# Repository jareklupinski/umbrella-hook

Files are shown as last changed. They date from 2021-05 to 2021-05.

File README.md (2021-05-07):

# umbrella-hook
Umbrella hook is a wall-mounted umbrella docking solution that interacts with AI-enhanced Weather Forecasting Services to notify the user of impending sky hydration by emitting a pleasing blue glow.

The intention is that as you glance at your umbrella on your way out the door, if the umbrella-hook is blue, you grab your umbrella.

## How it works

Umbrella-hook contains a small circuit board running a simple program that:
- Offers an interface for connecting umbrella-hook to a WiFi router and setting the umbrella-hook location
- Makes a GET request with the provided location to an API that responds with whether there will be rain in that area, and in how many hours

The umbrella-hook then turns on the on-board LED if the returned hours value overlaps the user's chosen "Rain Warning Time" (default to 6 hours).

Housing:

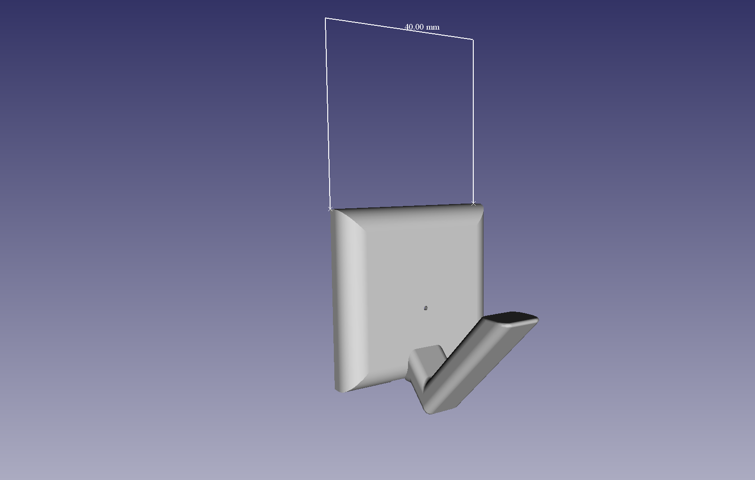
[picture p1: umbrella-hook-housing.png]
housing


Housing Wireframe:

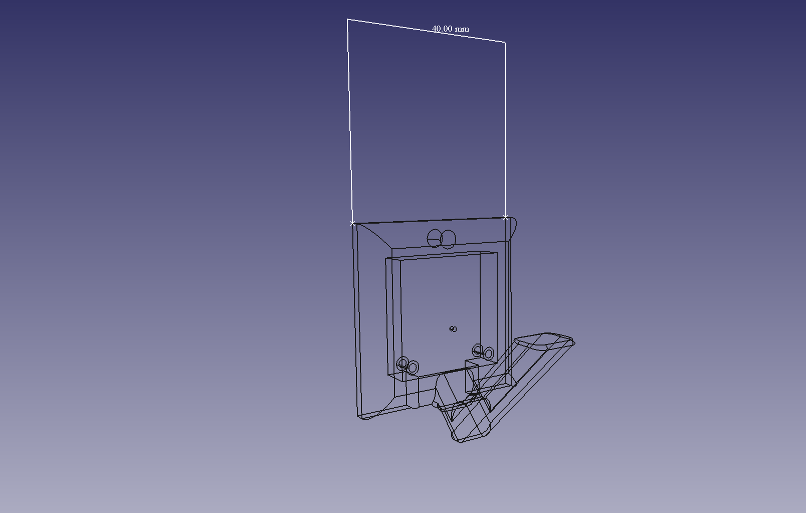
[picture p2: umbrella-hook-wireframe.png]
wireframe


Circuit Board:

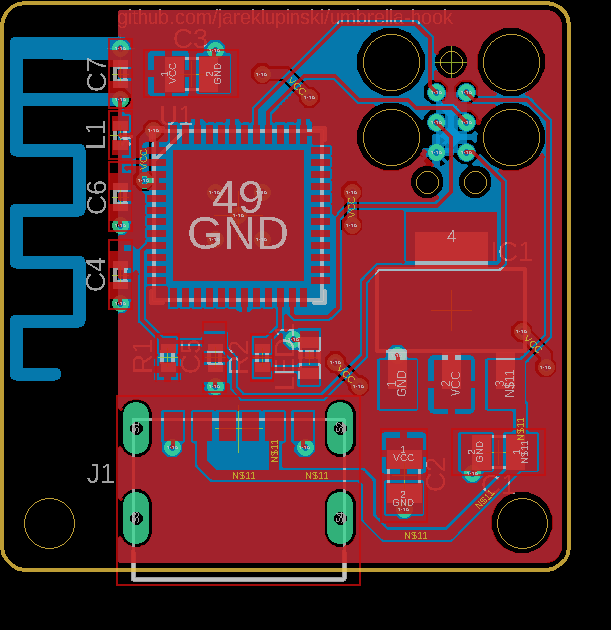
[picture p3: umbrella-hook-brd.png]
board


Schematic:

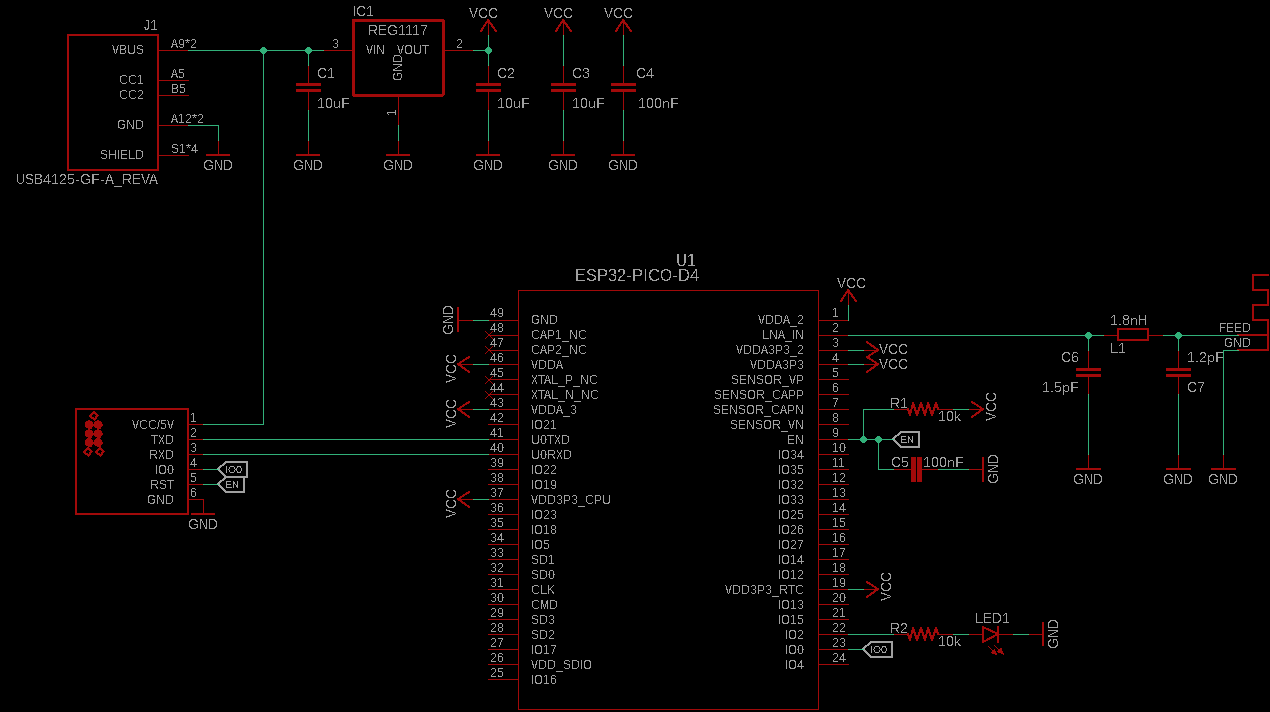
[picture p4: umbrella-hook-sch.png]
schematic


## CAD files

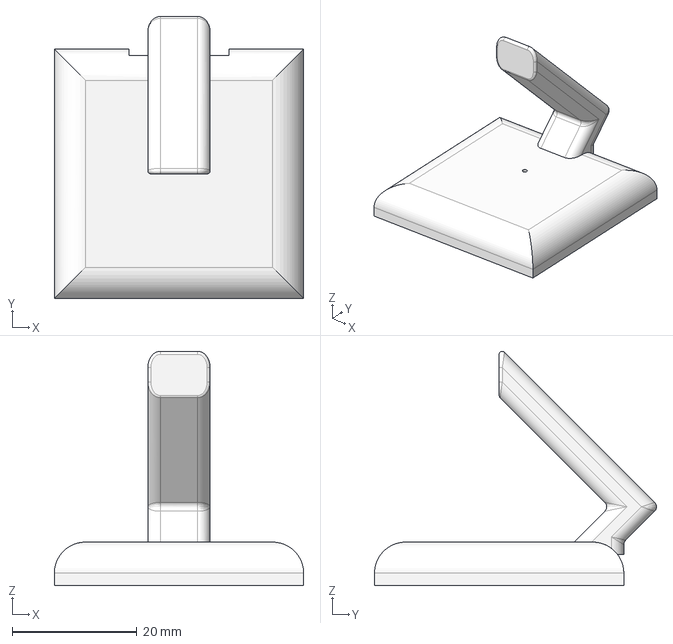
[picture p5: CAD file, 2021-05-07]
umbrella-hook-housing.step
40.0 x 45.2 x 37.6 mm

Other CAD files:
umbrella-hook.FCStd

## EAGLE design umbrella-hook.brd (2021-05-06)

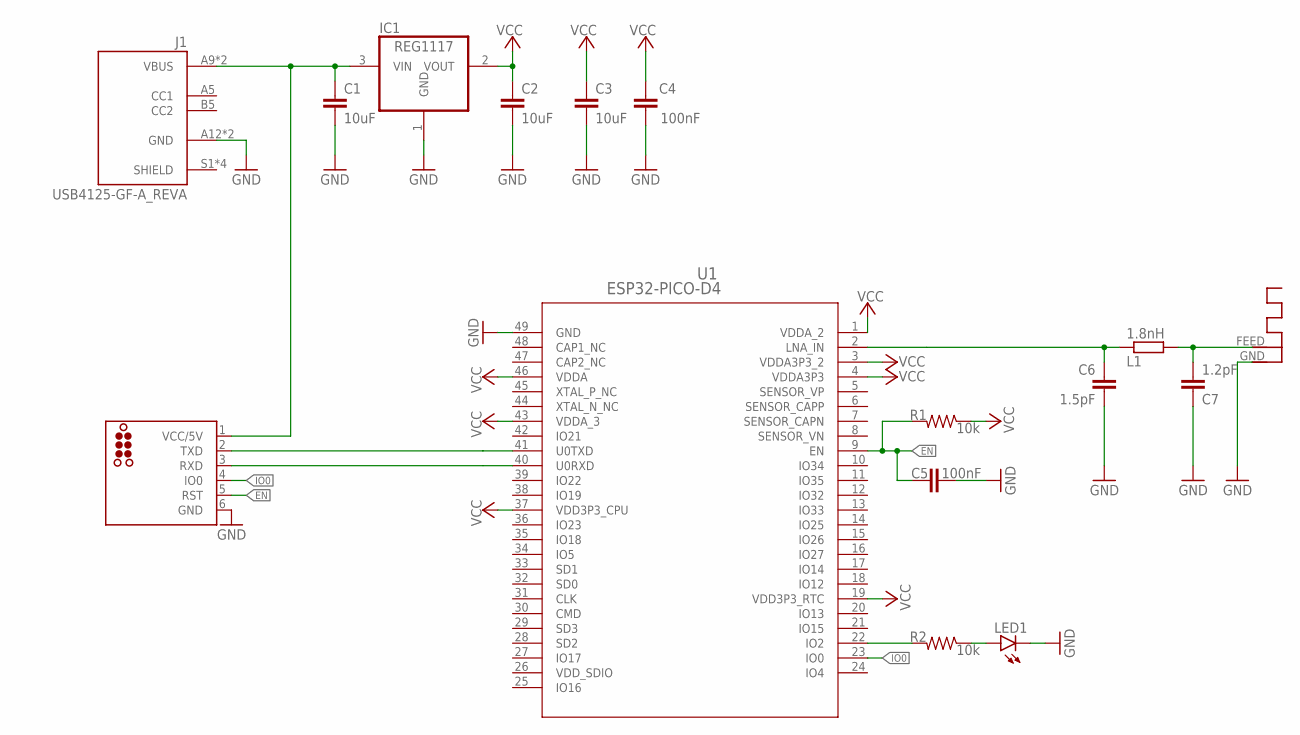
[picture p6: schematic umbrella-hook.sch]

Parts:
ANT1: ANTENNA; RN-ANT
C1, C2, C3: 10uF; C0805
C4, C5: 100nF; C0402
C6: 1.5pF; C0402
C7: 1.2pF; C0402
IC1: REG1117; SOT223
J1: USB4125-GF-A_REVA; GCT_USB4125-GF-A_REVA
J2: TC2030-ESP; TC2030-MCP
L1: 1.8nH; R0402
LED1: LEDCHIP-LED0603; CHIP-LED0603
R1, R2: 10k; R0402
U1: ESP32-PICO-D4; ESP32-PICO-D4_EXP

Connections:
EN: C5.2, J2.5 (RST), R1.2, U1.9 (EN)
GND: ANT1.GND, C1.2, C2.2, C3.2, C4.2, C5.1, C6.2, C7.1, IC1.1 (GND), J1.A12 (GND), J1.B12 (GND), J2.6 (GND), LED1.C, U1.49 (GND)
IO0: J2.4 (IO0), U1.23 (IO0)
unnamed: ANT1.FEED, C7.2, L1.2
unnamed: C6.1, L1.1, U1.2 (LNA_IN)
unnamed: R2.2, U1.22 (IO2)
unnamed: LED1.A, R2.1
unnamed: C1.1, IC1.3 (VIN), J1.A9 (VBUS), J1.B9 (VBUS), J2.1 (VCC/5V)
unnamed: J2.2 (TXD), U1.41 (U0TXD)
unnamed: J2.3 (RXD), U1.40 (U0RXD)
VCC: C2.1, C3.1, C4.1, IC1.2 (VOUT), R1.1, U1.1 (VDDA_2), U1.3 (VDDA3P3_2), U1.4 (VDDA3P3), U1.19 (VDD3P3_RTC), U1.37 (VDD3P3_CPU), U1.43 (VDDA_3), U1.46 (VDDA)
VDD_SDIO: U1.26 (VDD_SDIO)

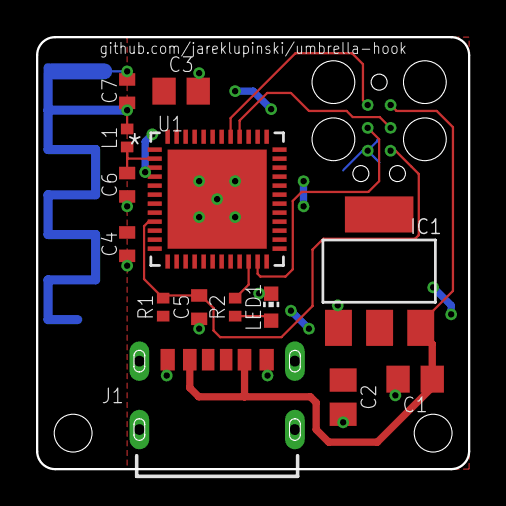
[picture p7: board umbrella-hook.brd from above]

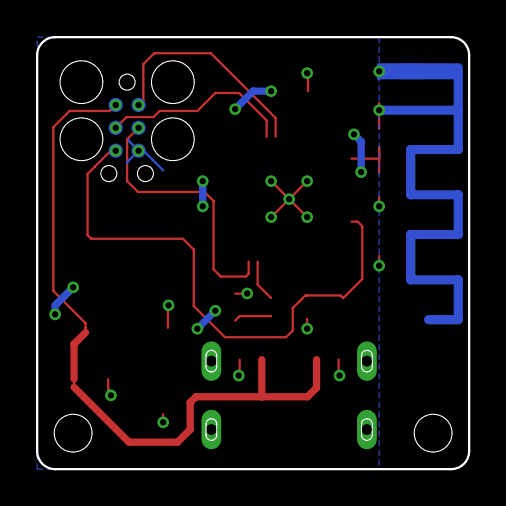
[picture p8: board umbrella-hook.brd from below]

Board: 2 copper layers, 24.0 x 24.0 mm, 16 parts (2 on the bottom side), 11 nets.

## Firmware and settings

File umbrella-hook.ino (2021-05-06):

#include <WiFi.h>

#define LED_PIN 2

const char* ssid     = "your-ssid";
const char* password = "your-pass";
const uint16_t zip   = 10001;

const char* host = "umbrella-hook.herokuapp.com";
const uint16_t port = 80;

void setup() {
  // Init Board
  Serial.begin(115200);
  pinMode(LED_PIN, OUTPUT);

  // Start WiFi
  // TODO pick a WiFi provisioning flow
  // https://docs.espressif.com/projects/esp-idf/en/latest/esp32/api-reference/provisioning/provisioning.html
  WiFi.begin(ssid, password);

  // Wait for connection
  Serial.print("Waiting for WiFi");
  while(WiFi.status() != WL_CONNECTED) {
    Serial.print(".");
    delay(500);
  }
  Serial.println("WiFi connected");
}

void loop() {
  Serial.print("Connecting to ");
  Serial.println(host);

  // Start HTTP Client
  WiFiClient client;
  if (!client.connect(host, port)) {
    Serial.println("Connection failed.");
    delay(5000);
    return;
  }

  // Send request to Server via Client
  client.print(String("GET ") + "http://" + host + "/" + zip + " HTTP/1.0\r\n" +
     "Host: " + host + "\r\n" +
     "Connection: close\r\n\r\n");

  // Wait for response from Server
  unsigned long timeout = millis();
  while (client.available() == 0) {
    if (millis() - timeout > 5000) {
      Serial.println(">>> Client Timeout !");
      client.stop();
      return;
    }
  }

  // Parse response from Server and glow blue if "rain"
  digitalWrite(LED_PIN, LOW);
  while(client.available()) {
    String line = client.readStringUntil('\r');
    Serial.print(line);
    if (line == "rain") {
      digitalWrite(LED_PIN, HIGH);
    }
  }
  
  Serial.println("Waiting 30 seconds before restarting...");
  delay(30000);
}

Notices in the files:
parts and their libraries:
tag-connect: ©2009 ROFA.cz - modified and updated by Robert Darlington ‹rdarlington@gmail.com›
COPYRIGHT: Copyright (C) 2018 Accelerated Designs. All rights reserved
